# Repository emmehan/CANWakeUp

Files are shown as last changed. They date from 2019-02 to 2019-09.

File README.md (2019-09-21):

Work in progress

# CAN WakeUp

Build Status (http://ci.jonasheim.de/job/CANWakeUp/)

The intendation of this project is to create a device that will act as a Wake-Up source for CAN devices.
A microcontroller ([STM32F103](https://www.st.com/en/microcontrollers/stm32f103c8.html)) sends a cyclic CAN messages using an external CAN transceiver ([TJA1050](https://www.nxp.com/docs/en/data-sheet/TJA1050.pdf)).

This project includes the EAGLE schematic and layout files among the source code for the microcontroller.

# Project structure

## Hardware
@TODO

## Software
Big shout-out to Patrik Jaworski for his [blog post](http://regalis.com.pl/en/arm-cortex-stm32-gnulinux/) about the initial bring up of the STM32Fx.
It really helped me to get back on track after a longer absence from the STM32 device family.

The software is based on the [STM32CubeF1 MCu Package ](https://www.st.com/en/embedded-software/stm32cubef1.html) from ST Microelectronis.
The application software is based on the ARM CMSIS library for the STM32F103C8T6 device.

It is developed on Linux (Arch-Linux, Kernel 4.19.2) using the GNU ARM toolchain(gcc-arm-none-eabi-*).

---

### Build

To build the firmware run:

    make -C ./Software MAIN=FW_NAME
in directory.

The `MAIN` parameter is optional and used to define the firmware name.

It defaults to `CANWakeUp`.

---

### Flash

To flash the firmare to the controller run:

    openocd -f interface/stlink-v2-1.cfg -f target/stm32f1x.cfg -c "program ./build/$FW_NAME.hex  verify reset exit"
while substitute `$FW_NAME` to the correct firmware filename.

There are preconfigured tasks for Visual Studio Code available for Building, Cleaning, Flashing and Debugging (using the [Cortex-Debug](https://marcelball.ca/projects/cortex-debug) extension by marus25).

---

### Software Documentation

To build the documentation run (requires [Doxygen](http://doxygen.nl/)):

    make doc

The documentation will then be available in `./doc/html/index.html`.

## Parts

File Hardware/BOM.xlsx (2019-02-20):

CANWakeUp BOM
Domain | ID | Name | Device | Link | Price
Power Supply | IC4 | Linear Power Regulator 5V | Texas Instruments LM1117MP-5.0 | Reichelt (https://www.reichelt.de/spannungsregler-low-drop-sot-223-lm-1117-mp5-0-p109330.html?&trstct=pos_0) | 0.86 €
 | IC5 | Linear Power Regulator 3V3 | Texas Instruments LM1117MP-3.3 | Reichelt (https://www.reichelt.de/ldo-spannungsregler-3-3-v-sot-223-lm-1117-mpx-3-3-p187608.html?&trstct=pos_3) | 0.86 €
MCU | IC1 | Microcontroller | STM32F103C8T6 32-Bit Flash-Microcontroller CORTEX-M3,LQFP48 | Reichelt (https://www.reichelt.de/32-bit-flash-microcontroller-cortex-m3-lqfp48-stm32-f103c8t6-p125398.html?trstct=pos_5) | 3.99 €
CAN | DA1 | CAN Transceiver | TJA1050 Schnittstellen-IC, CAN, SOT-96-1 | Reichelt (https://www.reichelt.de/schnittstellen-ic-can-sot-96-1-tja-1050-t-cm118-p188958.html?&trstct=pos_0) | 0.79 €
Miscellaneous | SWITCH | Switch | Schiebeschalter-Miniatur, Lötanschluss, 2x UM sw | Reichelt (https://www.reichelt.de/schiebeschalter-miniatur-loetanschluss-2x-um-sw-t-217-p19976.html?trstct=pol_13) | 0.33 €
 | LED1 | Power LED Red | Kingbright LED SMD 0805, rot, 12 mcd, 120° | Reichelt (https://www.reichelt.de/led-smd-0805-rot-12-mcd-120-kbt-kp-2012ec-p231678.html?&trstct=pol_4) | 0.10 €
 | LED2 | TX LED Green | Kingbright LED SMD 0805, green, 12mcd, 120° | Reichelt (https://www.reichelt.de/led-smd-0805-gruen-12-mcd-120-kbt-kp-2012sgc-p231702.html?&trstct=pol_6) | 0.10 €
 | DSUB-9 | DSUB-9 Stecker | D-SUB-Stecker, 9-polig, gewinkelt, RM 2,77 | Reichelt (https://www.reichelt.de/d-sub-stecker-9-polig-gewinkelt-rm-2-77-d-sub-st-09eu-p6986.html?trstct=pol_3) | 0.40 €
 | Q1 | XTAL | SMD-Quarz, Grundton, 8,000000 MHz | Reichelt (https://www.reichelt.de/smd-quarz-grundton-8-000000-mhz-8-0000-hc49-smd-p72510.html?&trstct=pol_2) | 0.25 €
Resistors | R1 | R0805 | SMD-Widerstand, 0805, 10 kOhm, 125 mW, 1% | Reichelt (https://www.reichelt.de/smd-widerstand-0805-10-kohm-125-mw-1-smd-0805-10-0k-p32898.html?trstct=pol_0) | 0.03 €
 | R2 | R0805 | SMD-Widerstand, 0805, 68 Ohm, 125 mW, 1% | Reichelt (https://www.reichelt.de/smd-widerstand-0805-68-ohm-125-mw-1-smd-0805-68-0-p32872.html?&trstct=pol_0) | 0.03 €
 | R3 | R0805 | SMD-Widerstand, 0805, 56 Ohm, 125 mW, 1% | Reichelt (https://www.reichelt.de/smd-widerstand-0805-56-ohm-125-mw-1-smd-0805-56-0-p32871.html?&trstct=pol_0) | 0.03 €
 | R4 | R0805 | SMD-Widerstand, 0805, 390 Ohm, 125 mW, 1% | Reichelt (https://www.reichelt.de/smd-widerstand-0805-390-ohm-125-mw-1-smd-0805-390-p32881.html?&trstct=pol_0) | 0.03 €
 | R5 | R0805 | SMD-Widerstand, 0805, 10 kOhm, 125 mW, 1% | Reichelt (https://www.reichelt.de/smd-widerstand-0805-10-kohm-125-mw-1-smd-0805-10-0k-p32898.html?trstct=pol_0) | 0.03 €
 | R6 | R0805 | SMD-Widerstand, 0805, 10 kOhm, 125 mW, 1% | Reichelt (https://www.reichelt.de/smd-widerstand-0805-10-kohm-125-mw-1-smd-0805-10-0k-p32898.html?trstct=pol_0) | 0.03 €
 | R7 | R0805 | SMD-Widerstand, 0805, 10 kOhm, 125 mW, 1% | Reichelt (https://www.reichelt.de/smd-widerstand-0805-10-kohm-125-mw-1-smd-0805-10-0k-p32898.html?trstct=pol_0) | 0.03 €
Capacitors | C1 | C0805 | SMD-Vielschicht-Keramikkondensator 10N, 10% | Reichelt (https://www.reichelt.de/smd-vielschicht-keramikkondensator-10n-10-x7r-g0805-10n-p22877.html?trstct=pol_0) | 0.02 €
 | C2 | C0805 | SMD-Vielschicht-Keramikkondensator 10N, 10% | Reichelt (https://www.reichelt.de/smd-vielschicht-keramikkondensator-10n-10-x7r-g0805-10n-p22877.html?trstct=pol_0) | 0.02 €
 | C3 | C0805 | SMD-Vielschicht-Keramikkondensator 10N, 10% | Reichelt (https://www.reichelt.de/smd-vielschicht-keramikkondensator-10n-10-x7r-g0805-10n-p22877.html?trstct=pol_0) | 0.02 €
 | C4 | C0805 | SMD-Vielschicht-Keramikkondensator 10N, 10% | Reichelt (https://www.reichelt.de/smd-vielschicht-keramikkondensator-10n-10-x7r-g0805-10n-p22877.html?trstct=pol_0) | 0.02 €
 | C5 | C0805 | SMD-Vielschicht-Keramikkondensator 10N, 10% | Reichelt (https://www.reichelt.de/smd-vielschicht-keramikkondensator-10n-10-x7r-g0805-10n-p22877.html?trstct=pol_0) | 0.02 €
 | C6 | C0805 | SMD-Vielschicht-Keramikkondensator 10N, 10% | Reichelt (https://www.reichelt.de/smd-vielschicht-keramikkondensator-10n-10-x7r-g0805-10n-p22877.html?trstct=pol_0) | 0.02 €
 | C7 | C0805 | SMD-Vielschicht-Keramikkondensator 10N, 10% | Reichelt (https://www.reichelt.de/smd-vielschicht-keramikkondensator-10n-10-x7r-g0805-10n-p22877.html?trstct=pol_0) | 0.02 €
 | C8 | C0805 | SMD-Vielschicht-Keramikkondensator 10N, 10% | Reichelt (https://www.reichelt.de/smd-vielschicht-keramikkondensator-10n-10-x7r-g0805-10n-p22877.html?trstct=pol_0) | 0.02 €
 | C9 | C0805 | SMD-Vielschicht-Keramikkondensator 10N, 10% | Reichelt (https://www.reichelt.de/smd-vielschicht-keramikkondensator-10n-10-x7r-g0805-10n-p22877.html?trstct=pol_0) | 0.02 €
 | C10 | C0805 | SMD-Kerko, 0805, 1 µF, 10 V, 10%, MLCC | Reichelt (https://www.reichelt.de/smd-kerko-0805-1-f-10-v-10-mlcc-rnd-1500805b1051-p226176.html?&trstct=pol_6) | 0.02 €
 | C11 | C0805 | SMD-Vielschicht-Keramikkondensator 100N, 10% | Reichelt (https://www.reichelt.de/smd-vielschicht-keramikkondensator-100n-10-x7r-g0805-100n-p31879.html?trstct=pol_0) | 0.07 €
 | C12 | C0805 | SMD-Vielschicht-Keramikkondensator 100N, 10% | Reichelt (https://www.reichelt.de/smd-vielschicht-keramikkondensator-100n-10-x7r-g0805-100n-p31879.html?trstct=pol_0) | 0.07 €
 | C13 | C0805 | SMD-Vielschicht-Keramikkondensator 22P, 5% | Reichelt (https://www.reichelt.de/smd-vielschicht-keramikkondensator-22p-5-npo-g0805-22p-p13517.html?trstct=pol_0) | 0.02 €
 | C14 | C0805 | SMD-Vielschicht-Keramikkondensator 22P, 5% | Reichelt (https://www.reichelt.de/smd-vielschicht-keramikkondensator-22p-5-npo-g0805-22p-p13517.html?trstct=pol_0) | 0.02 €
Summe/Muster | 8.27 €

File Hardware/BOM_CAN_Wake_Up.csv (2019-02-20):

Part | Value | Device | Package | Description | MF | MPN | OC_FARNELL | OC_NEWARK | TP_SIGNAL_NAME
C1 | 10nF | C-EUC0805 | C0805 | CAPACITOR, European symbol
C2 | 10nF | C-EUC0805 | C0805 | CAPACITOR, European symbol
C3 | 10nF | C-EUC0805 | C0805 | CAPACITOR, European symbol
C4 | 10uF | C-EUC0805 | C0805 | CAPACITOR, European symbol
C5 | 10uF | C-EUC0805 | C0805 | CAPACITOR, European symbol
C6 | 10uF | C-EUC0805 | C0805 | CAPACITOR, European symbol
C7 | 10uF | C-EUC0805 | C0805 | CAPACITOR, European symbol
C8 | 10uF | C-EUC0805 | C0805 | CAPACITOR, European symbol
C9 | 10nF | C-EUC0805 | C0805 | CAPACITOR, European symbol
C10 | 1uF | C-EUC0805 | C0805 | CAPACITOR, European symbol
C11 | 100nF | C-EUC0805 | C0805 | CAPACITOR, European symbol
C12 | 100nF | C-EUC0805 | C0805 | CAPACITOR, European symbol
C13 | 22pF | C-EUC0805 | C0805 | CAPACITOR, European symbol
C14 | 22pF | C-EUC0805 | C0805 | CAPACITOR, European symbol
DA1 | TJA1050 | TJA1050 | SO08 | High speed CAN transceiver
DBG_GND | TPB1,27 | TPB1,27 | B1,27 | Test pad
DBG_SWCLK | TPB1,27 | TPB1,27 | B1,27 | Test pad
DBG_SWDIO | TPB1,27 | TPB1,27 | B1,27 | Test pad
DBG_VCC_3V3 | TPB1,27 | TPB1,27 | B1,27 | Test pad
DSUB-9 | CAN | M09HPS | M09HP | SUB-D |  |  | unknown | unknown
GND |  | PINHD-1X1 | 1X01 | PIN HEADER
H1 | SPECIAL_DRILL_0.1000 | SPECIAL_DRILL_0.1000 | PAD_0.1000 | Special drills
H2 | SPECIAL_DRILL_0.1000 | SPECIAL_DRILL_0.1000 | PAD_0.1000 | Special drills
H3 | SPECIAL_DRILL_0.1000 | SPECIAL_DRILL_0.1000 | PAD_0.1000 | Special drills
H4 | SPECIAL_DRILL_0.1000 | SPECIAL_DRILL_0.1000 | PAD_0.1000 | Special drills
IC1 | STM32F10XCXT6 | STM32F10XCXT6 | TQFP48 | ST STM32F101/103 48pin LQFP
IC4 | LM1117MP-5.0 | LM1117MP-5.0 | SOT223 | 800mA Low-Dropout Linear Regulator | Texas Instruments | LM1117MP-5.0 | 9778209 | 28X3417
IC5 | LM1117MP-3.3 | LM1117MP-3.3 | SOT223 | 800mA Low-Dropout Linear Regulator | Texas Instruments | LM1117MP-3.3 | 9778195 | 28X3416
KL30 |  | PINHD-1X1 | 1X01 | PIN HEADER
LED_PWR | RED | LEDSML0805 | SML0805 | LED
LED_TX | GREEN | LEDSML0805 | SML0805 | LED
Q1 | 8MHz | CRYSTALHC49UP | HC49UP | CRYSTAL |  |  | unknown | unknown
R1 | 10k | R-EU_R0805 | R0805 | RESISTOR, European symbol
R2 | 68 | R-EU_R0805 | R0805 | RESISTOR, European symbol
R3 | 56 | R-EU_R0805 | R0805 | RESISTOR, European symbol
R4 | 390 | R-EU_R0805 | R0805 | RESISTOR, European symbol
R5 | 10k | R-EU_R0805 | R0805 | RESISTOR, European symbol
R6 | 10k | R-EU_R0805 | R0805 | RESISTOR, European symbol
R7 | 10k | R-EU_R0805 | R0805 | RESISTOR, European symbol
R8 | 10k | R-EU_R0805 | R0805 | RESISTOR, European symbol
S1 | 9077-1 | 9077-1 | 9077-1 | MARQUARDT SWITCH 9077.0100

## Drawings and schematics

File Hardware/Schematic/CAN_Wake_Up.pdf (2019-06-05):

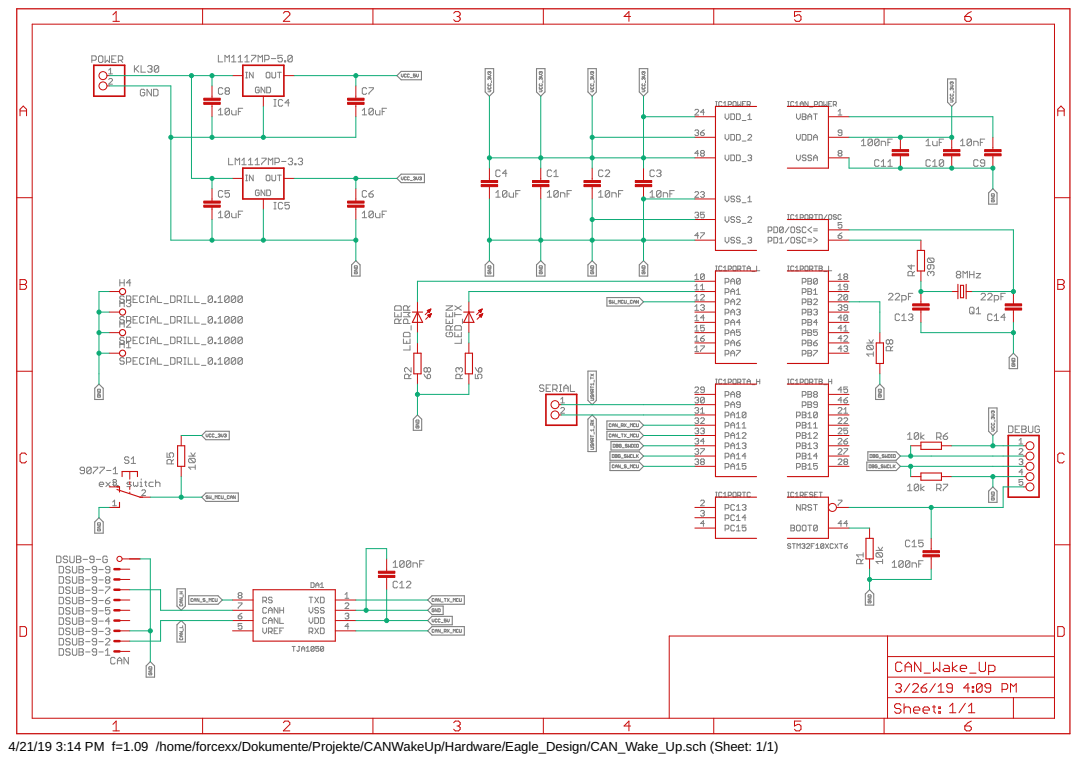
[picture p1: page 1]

4/21/19 3:14 PM f=1.09 /home/forcexx/Dokumente/Projekte/CANWakeUp/Hardware/Eagle_Design/CAN_Wake_Up.sch (Sheet: 1/1)

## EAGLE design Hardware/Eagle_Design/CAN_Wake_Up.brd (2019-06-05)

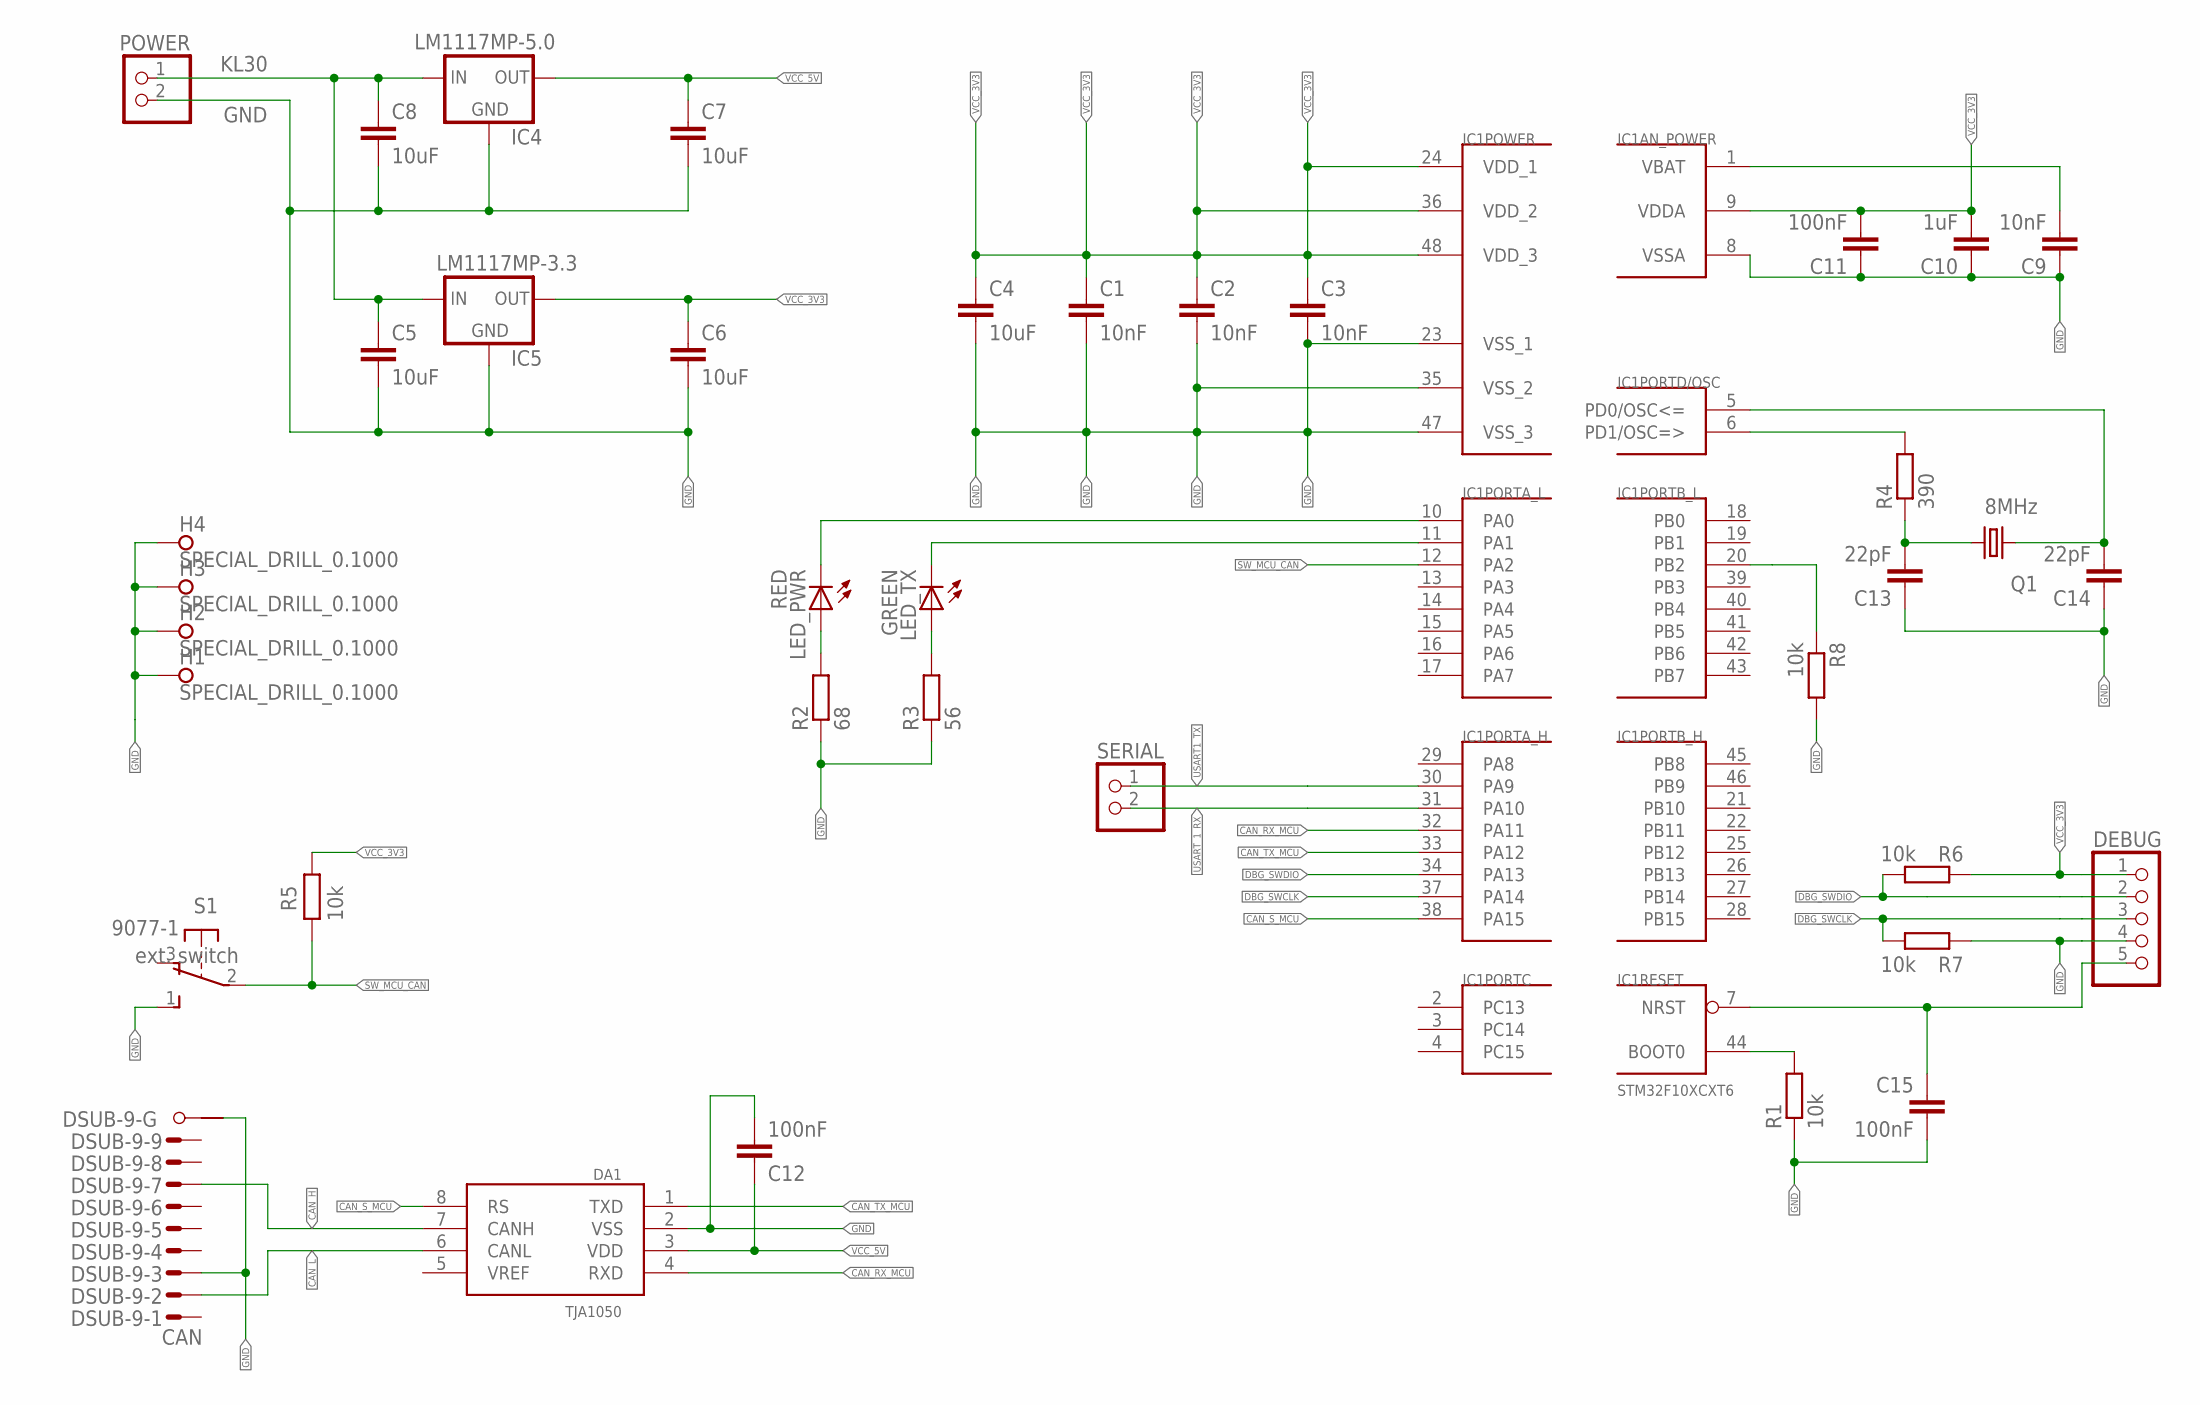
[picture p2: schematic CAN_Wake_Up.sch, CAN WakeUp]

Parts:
C1, C2, C3, C9: 10nF; C0805
C4, C5, C6, C7, C8: 10uF; C0805
C10: 1uF; C0805
C11, C12, C15: 100nF; C0805
C13, C14: 22pF; C0805
DA1: TJA1050; SO08
DEBUG: PINHD-1X5; 1X05
DSUB-9: CAN; M09HP
H1, H2, H3, H4: SPECIAL_DRILL_0.1000; PAD_0.1000
IC1: STM32F10XCXT6; TQFP48
IC4: LM1117MP-5.0; SOT223
IC5: LM1117MP-3.3; SOT223
LED_PWR: RED; SML0805
LED_TX: GREEN; SML0805
POWER: PINHD-1X2; 1X02
Q1: 8MHz; HC49UP
R1, R5, R6, R7, R8: 10k; R0805
R2: 68; R0805
R3: 56; R0805
R4: 390; R0805
S1: 9077-1
SERIAL: PINHD-1X2; 1X02

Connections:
CAN_H: DA1.7 (CANH), DSUB-9.7 (M)
CAN_L: DA1.6 (CANL), DSUB-9.2 (M)
CAN_RX_MCU: DA1.4 (RXD), IC1.32 (PA11)
CAN_S_MCU: DA1.8 (RS), IC1.38 (PA15)
CAN_TX_MCU: DA1.1 (TXD), IC1.33 (PA12)
DBG_SWCLK: DEBUG.3, IC1.37 (PA14), R7.1
DBG_SWDIO: DEBUG.2, IC1.34 (PA13), R6.2
GND: C1.2, C2.2, C3.2, C4.2, C5.2, C6.2, C7.2, C8.2, C9.1, C10.1, C11.1, C12.2, C13.1, C14.1, C15.2, DA1.2 (VSS), DEBUG.4, DSUB-9.3 (M), DSUB-9.G1, H1.1, H2.1, H3.1, H4.1, IC1.8 (VSSA), IC1.23 (VSS_1), IC1.35 (VSS_2), IC1.47 (VSS_3), IC4.1 (GND), IC5.1 (GND), POWER.2, R1.1, R2.1, R3.1, R7.2, R8.2, S1.1 (S)
KL30: C5.1, C8.1, IC4.3 (IN), IC5.3 (IN), POWER.1
LED_MCU_CAN: IC1.11 (PA1), LED_TX.C
LED_MCU_PWR: IC1.10 (PA0), LED_PWR.C
unnamed: IC1.44 (BOOT0), R1.2
unnamed: C9.2, IC1.1 (VBAT)
unnamed: LED_PWR.A, R2.2
unnamed: LED_TX.A, R3.2
unnamed: C13.2, Q1.2, R4.1
unnamed: C14.2, IC1.5 (PD0/OSC<=), Q1.1
unnamed: IC1.6 (PD1/OSC=>), R4.2
unnamed: IC1.20 (PB2), R8.1
unnamed: C15.1, DEBUG.5, IC1.7 (NRST)
SW_MCU_CAN: IC1.12 (PA2), R5.1, S1.2
USART1_TX: IC1.30 (PA9), SERIAL.1
USART_1_RX: IC1.31 (PA10), SERIAL.2
VCC_3V3: C1.1, C2.1, C3.1, C4.1, C6.1, C10.2, C11.2, DEBUG.1, IC1.9 (VDDA), IC1.24 (VDD_1), IC1.36 (VDD_2), IC1.48 (VDD_3), IC5.2 (OUT), IC5.4 (OUT), R5.2, R6.1
VCC_5V: C7.1, C12.1, DA1.3 (VDD), IC4.2 (OUT), IC4.4 (OUT)

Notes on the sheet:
ext. switch

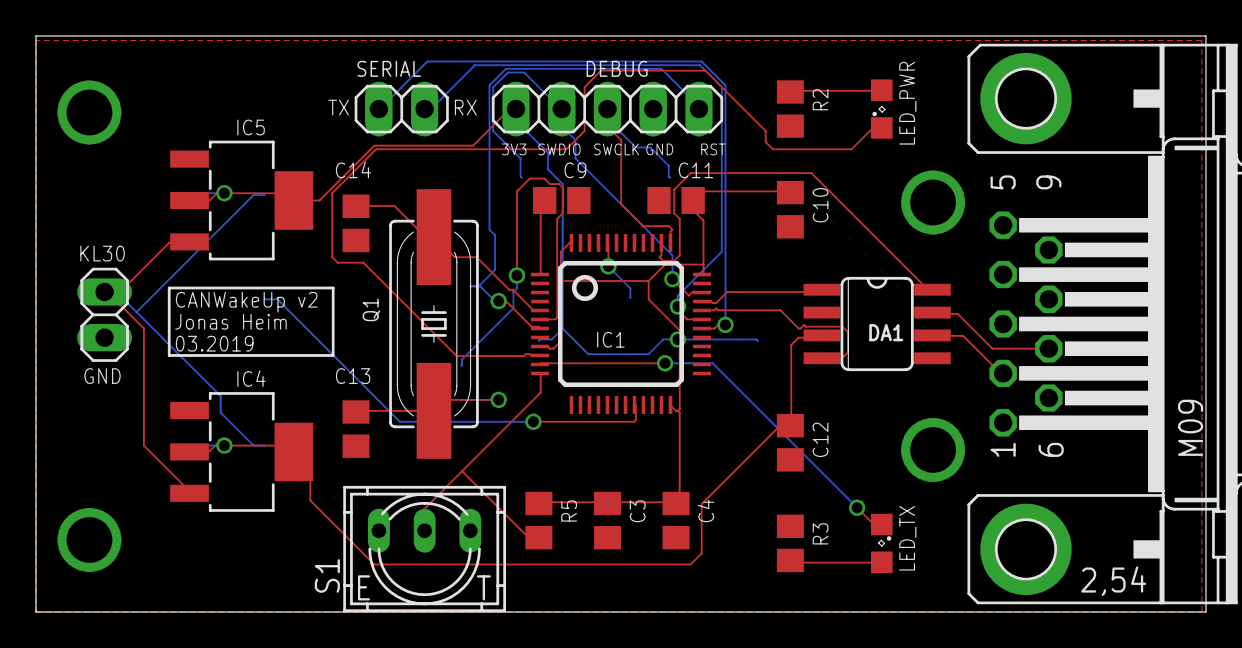
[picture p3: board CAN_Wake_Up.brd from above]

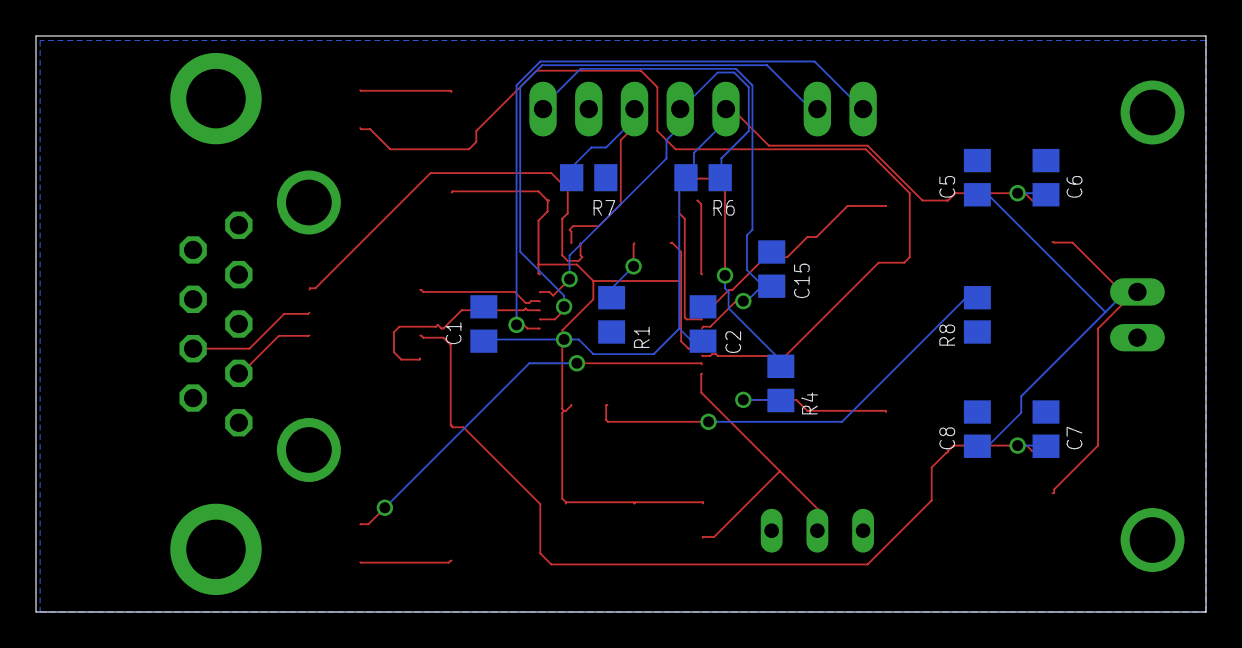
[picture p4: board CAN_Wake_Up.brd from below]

Board: 2 copper layers, 65.0 x 32.0 mm, 39 parts (12 on the bottom side), 25 nets.

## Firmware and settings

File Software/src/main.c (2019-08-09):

/**
  ******************************************************************************
  * @file    ADC/ADC_Regular_injected_groups/Src/main.c
  * @author  MCD Application Team
  * @version V1.5.0
  * @date    14-April-2017
  * @brief   This example provides a short description of how to use the ADC
  *          peripheral to perform conversions using the 2 ADC groups: 
  *          group regular for ADC conversions on main stream and 
  *          group injected for ADC conversions limited on specific events
  *          (conversions injected within main conversions stream). Other 
  *          peripherals used: DMA, TIM (ADC group regular conversions 
  *          triggered  by TIM, ADC group regular conversion data
  *          transfered by DMA).
  ******************************************************************************
  * @attention
  *
  * <h2><center>&copy; COPYRIGHT(c) 2016 STMicroelectronics</center></h2>
  *
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
  ******************************************************************************
  */

/* Includes ------------------------------------------------------------------*/
#include "main.h"

/* UART logging macro */
//#define BSP_LOG(x)  BSP_COM_Print(&UART1_Handle, x)
#define BSP_LOG(x)

void SystemClock_Config(void);
HAL_StatusTypeDef CAN_Send(CAN_HandleTypeDef* hcan, uint32_t* can_mailbox);

const UART_InitTypeDef UART1_Init = 
{
  .BaudRate     = 9600,
  .WordLength   = UART_WORDLENGTH_8B,
  .StopBits     = UART_STOPBITS_1,
  .Parity       = UART_PARITY_NONE,
  .Mode         = UART_MODE_TX_RX,
  .HwFlowCtl    = UART_HWCONTROL_NONE,
  .OverSampling = UART_OVERSAMPLING_16,
};

const CAN_InitTypeDef CAN1_Init = 
{
  .Prescaler = 4,
  .Mode = CAN_MODE_LOOPBACK,
  .SyncJumpWidth = CAN_SJW_1TQ,
  .TimeSeg1 = CAN_BS1_15TQ,
  .TimeSeg2 = CAN_BS1_2TQ,
  .TimeTriggeredMode = DISABLE,
  .AutoBusOff = DISABLE,
  .AutoWakeUp = ENABLE,
  .AutoRetransmission = DISABLE,
  .ReceiveFifoLocked = DISABLE,
  .TransmitFifoPriority = ENABLE,
};

uint8_t uart1_tx_buffer[100];
uint8_t uart1_rx_buffer[100];

UART_HandleTypeDef UART1_Handle;
CAN_HandleTypeDef CAN1_Handle;

/* FreeRTOS stuff */
void task_CAN(void*);
void task_2(void*);
#define STACK_SIZE 200
StackType_t xStack_task_CAN[ STACK_SIZE ];
StackType_t xStack_2[ STACK_SIZE ];

StaticTask_t xTaskBuffer_1, xTaskBuffer_2;

int main(void)
{
  UART1_Handle.Init         = UART1_Init;
  UART1_Handle.pTxBuffPtr   = uart1_tx_buffer;
  UART1_Handle.TxXferSize   = 100;
  UART1_Handle.TxXferCount  = 1;
  UART1_Handle.pRxBuffPtr   = uart1_rx_buffer;
  UART1_Handle.RxXferSize   = 100;
  UART1_Handle.RxXferCount  = 1;

  CAN1_Handle.Init = CAN1_Init;

  HAL_StatusTypeDef status_can_tx = HAL_ERROR;
  uint32_t can_tx_mailbox;

  SystemClock_Config();
  if(HAL_OK != HAL_Init())
  {
    while(1){};
  }

  PWR_PVDTypeDef pwrpvdstruct = {
    .PVDLevel = PWR_PVDLEVEL_7,
    .Mode = PWR_PVD_MODE_IT_RISING_FALLING,
  };

  __HAL_RCC_PWR_CLK_ENABLE();

  HAL_PWR_ConfigPVD(&pwrpvdstruct);

  HAL_NVIC_SetPriority(PVD_IRQn, 1, 1);
  HAL_NVIC_EnableIRQ(PVD_IRQn);

  HAL_PWR_EnablePVD();

  BSP_LED_Init(LED_RED);
  BSP_LED_Init(LED_GREEN);

  if(HAL_OK != BSP_COM_Init(COM0, &UART1_Handle))
  {
    while(1){};
  }

  if(HAL_OK != BSP_CAN_COM_Init(CAN_COM0, &CAN1_Handle))
  {
    while(1){};
  }

  if(HAL_OK != BSP_CAN_COM_FilterInit(CAN_COM0, &CAN1_Handle))
  {
    while(1){};
  }

  if(HAL_OK != BSP_CAN_COM_Start(CAN_COM0, &CAN1_Handle))
  {
    while(1){};
  }

  vTraceEnable(TRC_START);

  /*
   * FreeRTOS 
   */

  /* Create task 1 - CAN_Task */
  xTaskCreateStatic(task_CAN, "CAN task", STACK_SIZE, (void*) 1, tskIDLE_PRIORITY, xStack_task_CAN, &xTaskBuffer_1);

  /* Create task 2 - LED Red Blinky */
  xTaskCreateStatic(task_2, "LED_RED", STACK_SIZE, (void*) 1, 1, xStack_2, &xTaskBuffer_2);

  /* Start the FreeRTOS scheduler */
  vTaskStartScheduler();
}

void task_CAN(void* args)
{
  uint32_t can_tx_mailbox;
  HAL_StatusTypeDef status_can_tx = HAL_ERROR;
  while(1)
  {
    if(GPIO_PIN_SET == BSP_SW_GetState(SWITCH_USER))
    {
      BSP_LOG("Sending \r\n");
      BSP_LED_Toggle(LED_GREEN);
      status_can_tx = CAN_Send(&CAN1_Handle, &can_tx_mailbox);
    }
    else
    {
      BSP_LED_Off(LED_GREEN);
    }
    
    vTaskDelay(150/portTICK_PERIOD_MS);
  }
}

void task_2(void* args)
{
  while(1)
  {
    vTaskDelay(100/portTICK_PERIOD_MS);
    BSP_LED_Toggle(LED_RED);
  }
}

/*
 * Set SYSCLK   = 72MHz
 * Set APB1CLK  = 36MHz
 * Set APB2CLK  = 72MHz
 */
void SystemClock_Config(void)
{
  RCC_ClkInitTypeDef clkinitstruct = {0};
  RCC_OscInitTypeDef oscinitstruct = {0};
  
  /* Configure PLLs------------------------------------------------------*/
  /* PLL2 configuration: PLL2CLK=(HSE/HSEPrediv2Value)*PLL2MUL=(25/5)*8=40 MHz */
  /* PREDIV1 configuration: PREDIV1CLK = PLL2CLK / HSEPredivValue = 40 / 5 = 8 MHz */
  /* PLL configuration: PLLCLK = PREDIV1CLK * PLLMUL = 8 * 9 = 72 MHz */
  /* Enable HSE Oscillator and activate PLL with HSE as source */
  oscinitstruct.OscillatorType = RCC_OSCILLATORTYPE_HSE;
  oscinitstruct.HSEState = RCC_HSE_ON;
  oscinitstruct.HSEPredivValue = RCC_HSE_PREDIV_DIV1;
  oscinitstruct.PLL.PLLState = RCC_PLL_ON;
  oscinitstruct.PLL.PLLSource = RCC_PLLSOURCE_HSE;
  oscinitstruct.PLL.PLLMUL = RCC_PLL_MUL9;
  
  if (HAL_RCC_OscConfig(&oscinitstruct)!= HAL_OK)
  { /* Initialization Error */
    while(1);
  }
  
  /* Select PLL as system clock source and configure the HCLK, PCLK1 and PCLK2 clocks
  dividers */
  clkinitstruct.ClockType = (RCC_CLOCKTYPE_SYSCLK | RCC_CLOCKTYPE_HCLK |
  RCC_CLOCKTYPE_PCLK1 | RCC_CLOCKTYPE_PCLK2);
  clkinitstruct.SYSCLKSource = RCC_SYSCLKSOURCE_PLLCLK;
  clkinitstruct.AHBCLKDivider = RCC_SYSCLK_DIV1;
  clkinitstruct.APB2CLKDivider = RCC_HCLK_DIV1;
  clkinitstruct.APB1CLKDivider = RCC_HCLK_DIV2;
  
  if (HAL_RCC_ClockConfig(&clkinitstruct, FLASH_LATENCY_2)!= HAL_OK)
  { /* Initialization Error */
    while(1);
  }
}

HAL_StatusTypeDef CAN_Send(CAN_HandleTypeDef *hcan, uint32_t *can_mailbox)
{
  static CAN_TxHeaderTypeDef msg_can_tx_header = {
    .ExtId  = 0x14420FFF,
    .IDE    = CAN_ID_EXT,
    .RTR    = CAN_RTR_DATA,
    .DLC    = 8,
    .TransmitGlobalTime = DISABLE
  };

  static uint8_t msg_can_tx_data[] = 
  {
    0x55, 0xFF, 0xFF, 0xFF,
    0xFF, 0xFF, 0xFF, 0xFF
  };

  return HAL_CAN_AddTxMessage(hcan, &msg_can_tx_header, msg_can_tx_data, can_mailbox);
}

void PVD_IRQHandler(void)
{
  HAL_PWR_PVD_IRQHandler();
}

void HAL_PWR_PVDCallback(void)
{
  BSP_LOG("Undervoltage <2.9V detected!\r\n");
  BSP_LED_On(LED_RED);
}

void USB_HP_CAN1_TX_IRQHandler(void)
{
  HAL_CAN_IRQHandler(&CAN1_Handle);
}

void USB_LP_CAN1_RX0_IRQHandler(void)
{
  HAL_CAN_IRQHandler(&CAN1_Handle);
}

void CAN1_RX1_IRQHandler(void)
{
  HAL_CAN_IRQHandler(&CAN1_Handle);
}

void CAN1_SCE_IRQHandler(void)
{
  HAL_CAN_IRQHandler(&CAN1_Handle);
}

void HAL_CAN_TxMailbox0CompleteCallback(CAN_HandleTypeDef *hcan)
{
  BSP_LED_Toggle(LED_GREEN);
  BSP_LOG("CAN TX MB0 complete.\r\n");
}

void HAL_CAN_TxMailbox1CompleteCallback(CAN_HandleTypeDef *hcan)
{
  BSP_LED_Toggle(LED_GREEN);
  BSP_LOG("CAN TX MB1 complete.\r\n");
}

void HAL_CAN_TxMailbox2CompleteCallback(CAN_HandleTypeDef *hcan)
{
  BSP_LED_Toggle(LED_GREEN);
  BSP_LOG("CAN TX MB2 complete.\r\n");
}

void HAL_CAN_RxFifo0MsgPendingCallback(CAN_HandleTypeDef *hcan)
{
  static CAN_RxHeaderTypeDef can_rx_header;
  static CAN_TxHeaderTypeDef can_tx_header;
  static uint32_t can_tx_mailbox;
  static uint8_t can_rx_data[8];

  BSP_LOG("CAN RX FIFO 0\r\n");
  /* Read message and echo back with ID+1 */
  HAL_CAN_GetRxMessage(hcan, 0, &can_rx_header, can_rx_data);

  if(0x7FF == can_rx_header.StdId)
  {
    can_tx_header.StdId = 0;
  }
  else
  {
    can_tx_header.StdId = can_rx_header.StdId + 1;
  }
  can_tx_header.IDE    = can_rx_header.IDE;
  can_tx_header.RTR    = can_rx_header.RTR;
  can_tx_header.DLC    = can_rx_header.DLC;

  HAL_CAN_AddTxMessage(hcan, &can_tx_header, can_rx_data, &can_tx_mailbox);
}

void HAL_CAN_RxFifo1MsgPendingCallback(CAN_HandleTypeDef *hcan)
{
  BSP_LOG("CAN RX FIFO 1\r\n");
}

void HAL_CAN_ErrorCallback(CAN_HandleTypeDef *hcan)
{
  BSP_LOG("CAN Error - CAN state: ");
  char can_status[2] = {(char)(48+hcan->State), '\0'};  //48 = 0x30 = '0' ASCII
  BSP_LOG(can_status);
  BSP_LOG("\r\n");

  /* On error switch on LED_RED and switch off LED_GREEN */
  BSP_LED_On(LED_RED);
  BSP_LED_Off(LED_GREEN);
}

void vApplicationGetIdleTaskMemory( StaticTask_t **ppxIdleTaskTCBBuffer,
                                    StackType_t **ppxIdleTaskStackBuffer,
                                    uint32_t *pulIdleTaskStackSize )
{
/* If the buffers to be provided to the Idle task are declared inside this
function then they must be declared static - otherwise they will be allocated on
the stack and so not exists after this function exits. */
static StaticTask_t xIdleTaskTCB;
static StackType_t uxIdleTaskStack[ configMINIMAL_STACK_SIZE ];

    /* Pass out a pointer to the StaticTask_t structure in which the Idle task's
    state will be stored. */
    *ppxIdleTaskTCBBuffer = &xIdleTaskTCB;

    /* Pass out the array that will be used as the Idle task's stack. */
    *ppxIdleTaskStackBuffer = uxIdleTaskStack;

    /* Pass out the size of the array pointed to by *ppxIdleTaskStackBuffer.
    Note that, as the array is necessarily of type StackType_t,
    configMINIMAL_STACK_SIZE is specified in words, not bytes. */
    *pulIdleTaskStackSize = configMINIMAL_STACK_SIZE;
}

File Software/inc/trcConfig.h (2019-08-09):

/*******************************************************************************
 * Trace Recorder Library for Tracealyzer v4.3.5
 * Percepio AB, www.percepio.com
 *
 * trcConfig.h
 *
 * Main configuration parameters for the trace recorder library.
 * More settings can be found in trcStreamingConfig.h and trcSnapshotConfig.h.
 *
 * Read more at http://percepio.com/2016/10/05/rtos-tracing/
 *
 * Terms of Use
 * This file is part of the trace recorder library (RECORDER), which is the
 * intellectual property of Percepio AB (PERCEPIO) and provided under a
 * license as follows.
 * The RECORDER may be used free of charge for the purpose of recording data
 * intended for analysis in PERCEPIO products. It may not be used or modified
 * for other purposes without explicit permission from PERCEPIO.
 * You may distribute the RECORDER in its original source code form, assuming
 * this text (terms of use, disclaimer, copyright notice) is unchanged. You are
 * allowed to distribute the RECORDER with minor modifications intended for
 * configuration or porting of the RECORDER, e.g., to allow using it on a
 * specific processor, processor family or with a specific communication
 * interface. Any such modifications should be documented directly below
 * this comment block.
 *
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
 * Tabs are used for indent in this file (1 tab = 4 spaces)
 *
 * Copyright Percepio AB, 2018.
 * www.percepio.com
 ******************************************************************************/

#ifndef TRC_CONFIG_H
#define TRC_CONFIG_H

#ifdef __cplusplus
extern "C" {
#endif

#include "trcPortDefines.h"

/******************************************************************************
 * Include of processor header file
 *
 * Here you may need to include the header file for your processor. This is
 * required at least for the ARM Cortex-M port, that uses the ARM CMSIS API.
 * Try that in case of build problems. Otherwise, remove the #error line below.
 *****************************************************************************/
#include "stm32f1xx.h"

/*******************************************************************************
 * Configuration Macro: TRC_CFG_HARDWARE_PORT
 *
 * Specify what hardware port to use (i.e., the "timestamping driver").
 *
 * All ARM Cortex-M MCUs are supported by "TRC_HARDWARE_PORT_ARM_Cortex_M".
 * This port uses the DWT cycle counter for Cortex-M3/M4/M7 devices, which is
 * available on most such devices. In case your device don't have DWT support,
 * you will get an error message opening the trace. In that case, you may
 * force the recorder to use SysTick timestamping instead, using this define:
 *
 * #define TRC_CFG_ARM_CM_USE_SYSTICK
 *
 * For ARM Cortex-M0/M0+ devices, SysTick mode is used automatically.
 *
 * See trcHardwarePort.h for available ports and information on how to
 * define your own port, if not already present.
 ******************************************************************************/
#define TRC_CFG_HARDWARE_PORT TRC_HARDWARE_PORT_ARM_Cortex_M

/*******************************************************************************
 * Configuration Macro: TRC_CFG_RECORDER_MODE
 *
 * Specify what recording mode to use. Snapshot means that the data is saved in
 * an internal RAM buffer, for later upload. Streaming means that the data is
 * transferred continuously to the host PC.
 *
 * For more information, see http://percepio.com/2016/10/05/rtos-tracing/
 * and the Tracealyzer User Manual.
 *
 * Values:
 * TRC_RECORDER_MODE_SNAPSHOT
 * TRC_RECORDER_MODE_STREAMING
 ******************************************************************************/
#define TRC_CFG_RECORDER_MODE TRC_RECORDER_MODE_SNAPSHOT

/******************************************************************************
 * TRC_CFG_FREERTOS_VERSION
 *
 * Specify what version of FreeRTOS that is used (don't change unless using the
 * trace recorder library with an older version of FreeRTOS).
 *
 * TRC_FREERTOS_VERSION_7_3						If using FreeRTOS v7.3.x
 * TRC_FREERTOS_VERSION_7_4						If using FreeRTOS v7.4.x 
 * TRC_FREERTOS_VERSION_7_5_OR_7_6				If using FreeRTOS v7.5.0 - v7.6.0
 * TRC_FREERTOS_VERSION_8_X						If using FreeRTOS v8.X.X
 * TRC_FREERTOS_VERSION_9_0_0					If using FreeRTOS v9.0.0
 * TRC_FREERTOS_VERSION_9_0_1					If using FreeRTOS v9.0.1
 * TRC_FREERTOS_VERSION_9_0_2					If using FreeRTOS v9.0.2
 * TRC_FREERTOS_VERSION_10_0_0					If using FreeRTOS v10.0.0 or later
 *****************************************************************************/
#define TRC_CFG_FREERTOS_VERSION TRC_FREERTOS_VERSION_10_0_0
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

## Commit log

2018-12-17 Initial commit. Added Eagle project and a first draft of the schematic and BOM.
    [BOM.xlsx, CAN_Wake_Up.sch]
2018-12-17 Updated schematic.
2018-12-17 Added .gitignore for schematic subdir to exclude temp. Eagle files. Updated BOM. Added Eagle BOM textfile. Updated schematic. Added Debug interface.
    [BOM.xlsx, CAN_Wake_Up.sch]
2018-12-17 Reworked schematic. Added GND signal.
    [CAN_Wake_Up.sch]
2018-12-19 Renamed schematic and layout directory. Updated Schematic, replaced crystal with SMD variant. Added initial board layout file.
    [CAN_Wake_Up.brd, CAN_Wake_Up.sch]
2018-12-20 Moved schematic .pdf.
2018-12-27 Fixed wrong PLL/SYSCLK configuration - working now @ 32MHz SYSCLK. Added Clock-Out (MCO pin) to provide the SYSCLK (32MHz) on Pin A8. Added simple LED blinking on Pin A9. Replaced wrong ARM core head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
    [main.c]
2019-01-09 Started on PCB layout.
    [BOM.xlsx, CAN_Wake_Up.sch]
2019-01-10 Continued on layout. Not yet fully routable. PCB need to be resized.
    [CAN_Wake_Up.brd, CAN_Wake_Up.sch]
2019-01-12 Finished board layout. First order at seeedstudio.com
    [BOM.xlsx, CAN_Wake_Up.brd, CAN_Wake_Up.sch]
2019-02-03 New version. Added Eagle BOM (.csv) file.
    [BOM.xlsx, BOM_CAN_Wake_Up.csv, CAN_Wake_Up.brd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]
2019-02-07 Updated schematic PDF.
2019-02-14 Updated GPIOs to new board. Small blinking application.
2019-02-20 LED update in SW
2019-02-20 Started with implementing SysTick timer.
2019-03-03 A whole lot of updates... Added Link to Cortex-Debug extension for VSCode in README.md. Added Debug-Task for VSCode using said Cortex-Debug extension. Added STM32F10x Cortex-M3 Programming Manual. Fi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
    [main.c]
2019-03-05 Added LED blinking in TIM2 interrupt routine. Started with initialization of CAN peripheral.
2019-03-10 Fixed CAN signals (Tx and Rx switched). Added CAN bit timing configuration for 500kbit/s.
    [main.c]
2019-03-10 Fixed ignores again
    [CAN_Wake_Up.sch, CAN_Wake_Up_2.brd]
2019-03-13 Fixed GPIO initialization of SWITCH input and CAN RX/TX. Switch will now disable/enable LED blinking.
    [main.c]
2019-04-28 Latest hardware revision: rev2
    [CAN_Wake_Up.brd, CAN_Wake_Up.sch]
2019-06-11 Added STM32 HAL documents.
2019-06-12 Removed clean from all target in makefile. Fixed usage of application name in Flash task in tasks.json. Added correct device define. Added UART test. Added switch test.
    [main.c]
2019-06-27 CAN working bidirectional. Sends cyclic message every 100ms. A received message is echoed back with ID+1. Minimal CAN Error handling. Removed stm32f1xx_hal_msp.c file.
    [main.c]
2019-06-27 CANWakeUp working. Sends a WakeUp message every 1s. Switched mode to Loopback, since DUT is sending CAN-FD messages, trigger CAN errors.
    [main.c]
2019-07-01 Added PVD (programmable voltage detector). When a supply voltage of <2.9V is reached, an interrupt is triggered.
2019-07-05 Added FreeRTOS Tracing for Percepio. CAN not working on boards - investigation needed.
    [main.c, trcConfig.h]
